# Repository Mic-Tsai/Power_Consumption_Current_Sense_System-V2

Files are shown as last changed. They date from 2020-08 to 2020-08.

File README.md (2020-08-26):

## Power Consumption | Current Sense System V2



Arduino based power consumption calculator. Print results as UART interface and OLED display, also have SD card to log data.

Maximum 8 differential channels, come out with 4x ADS1115 in one I2C bus. RGB OLED display (ST7789 130x160) results show as a real-time update also supports the SD card data log. 

** **Important** **

Before you log the power consumption results, the resistor value needs to be calculated by the multimeter. You can press the button to do the value change very quickly! 

After the data logging into the SD card, plot data into an image via a python script.
## 

Any question or need technical support:

* Contact me via mail (xbcke12345@gmail.com)
* If this project helping. Please generously support =)

   

##

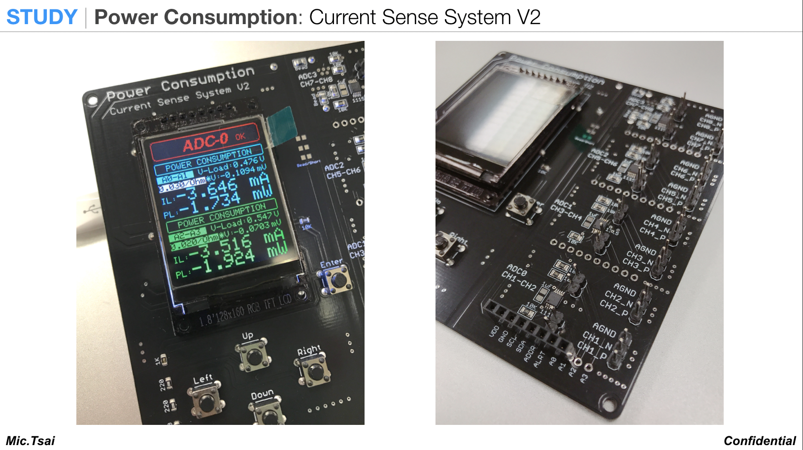
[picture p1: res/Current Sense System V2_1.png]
*Power Consumption | Current Sense System V2*

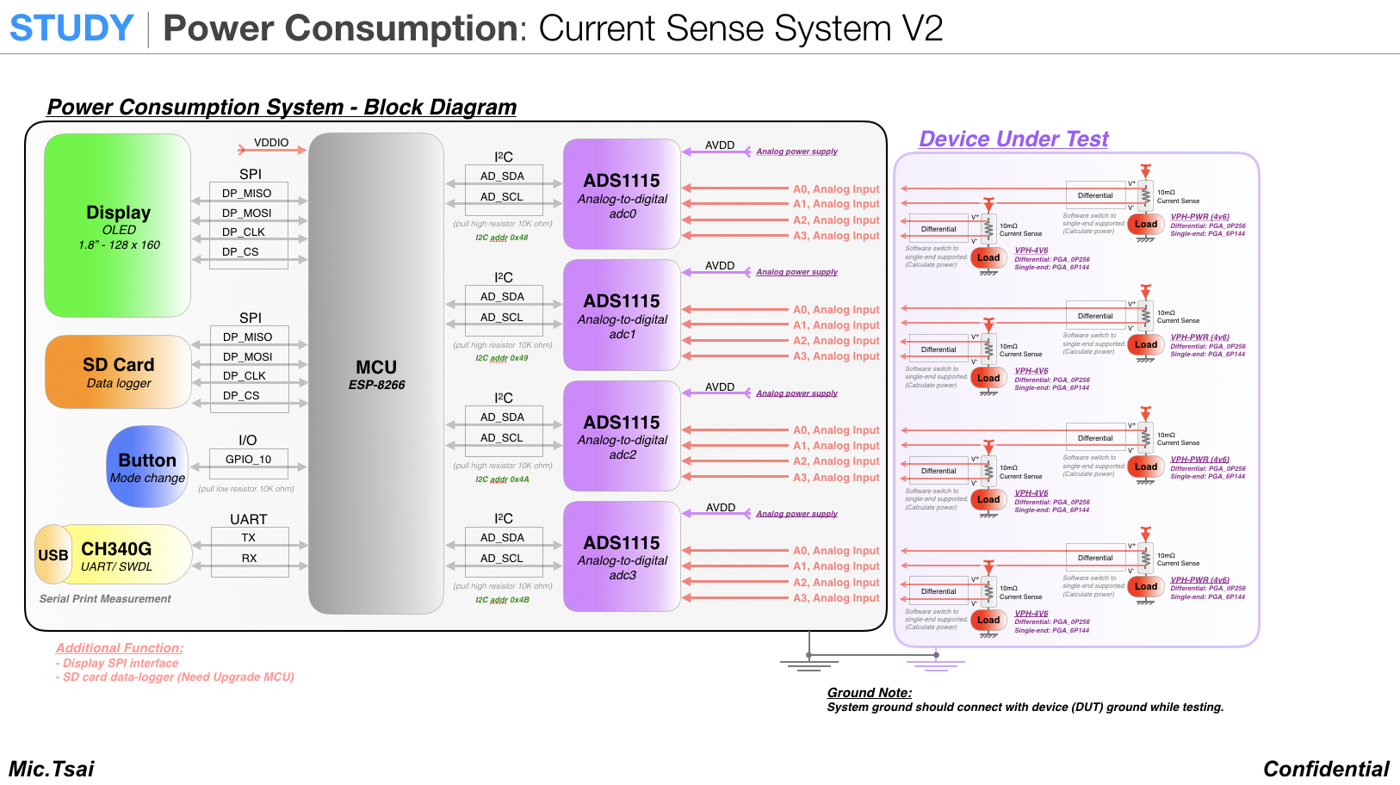
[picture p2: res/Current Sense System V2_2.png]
*Power Consumption | Current Sense System V2*

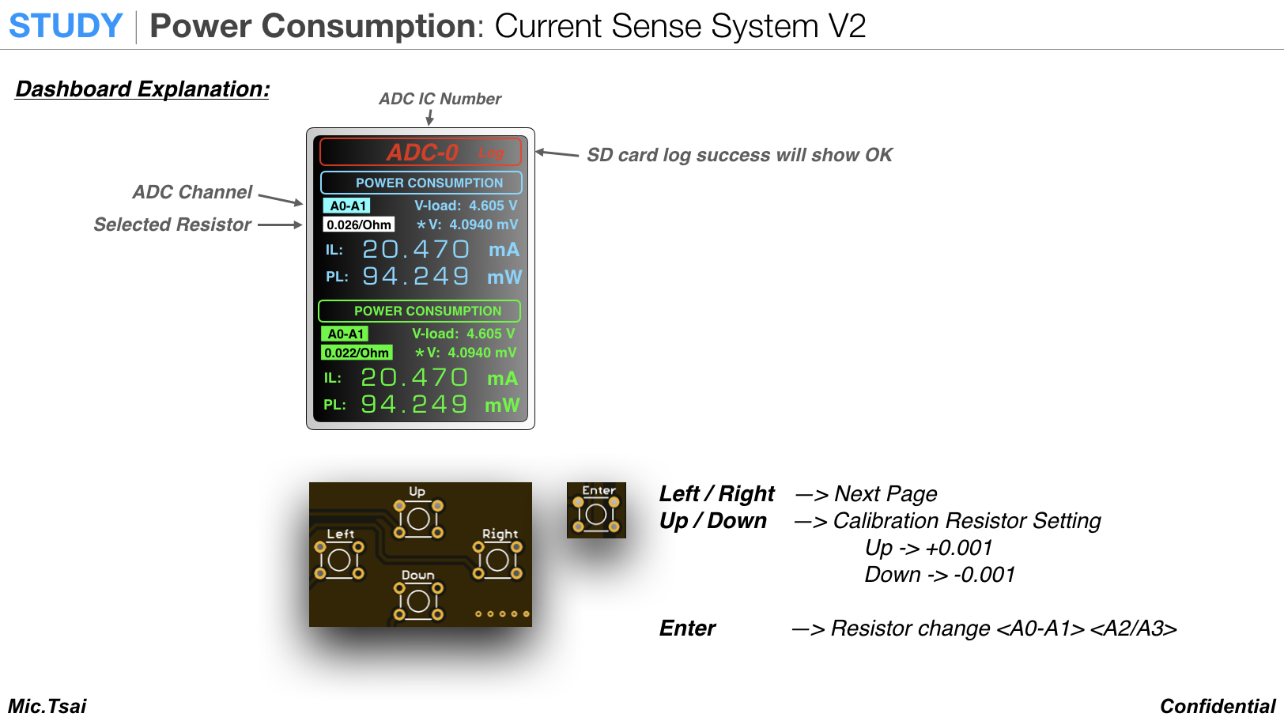
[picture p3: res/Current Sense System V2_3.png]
*Power Consumption | Current Sense System V2*

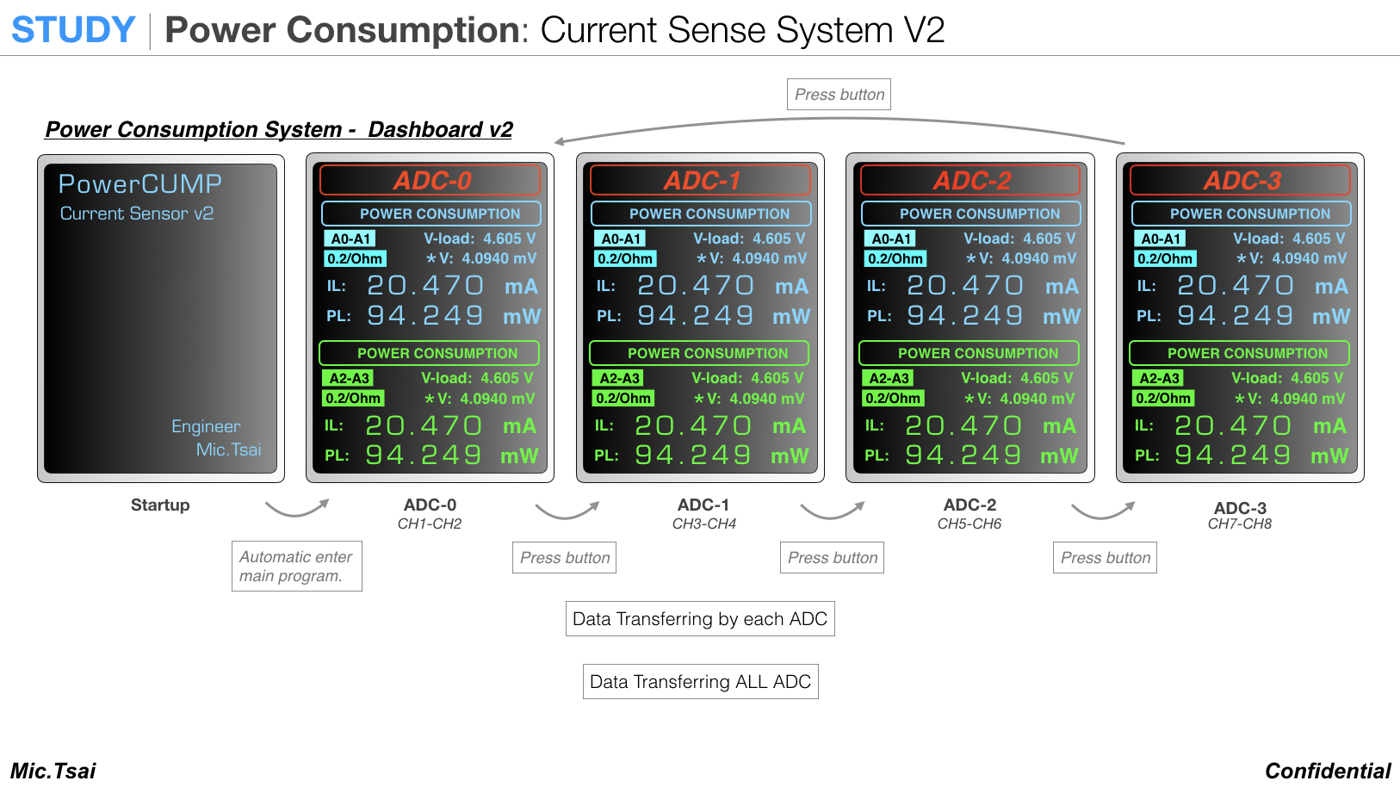
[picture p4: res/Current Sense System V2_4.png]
*Power Consumption | Current Sense System V2*

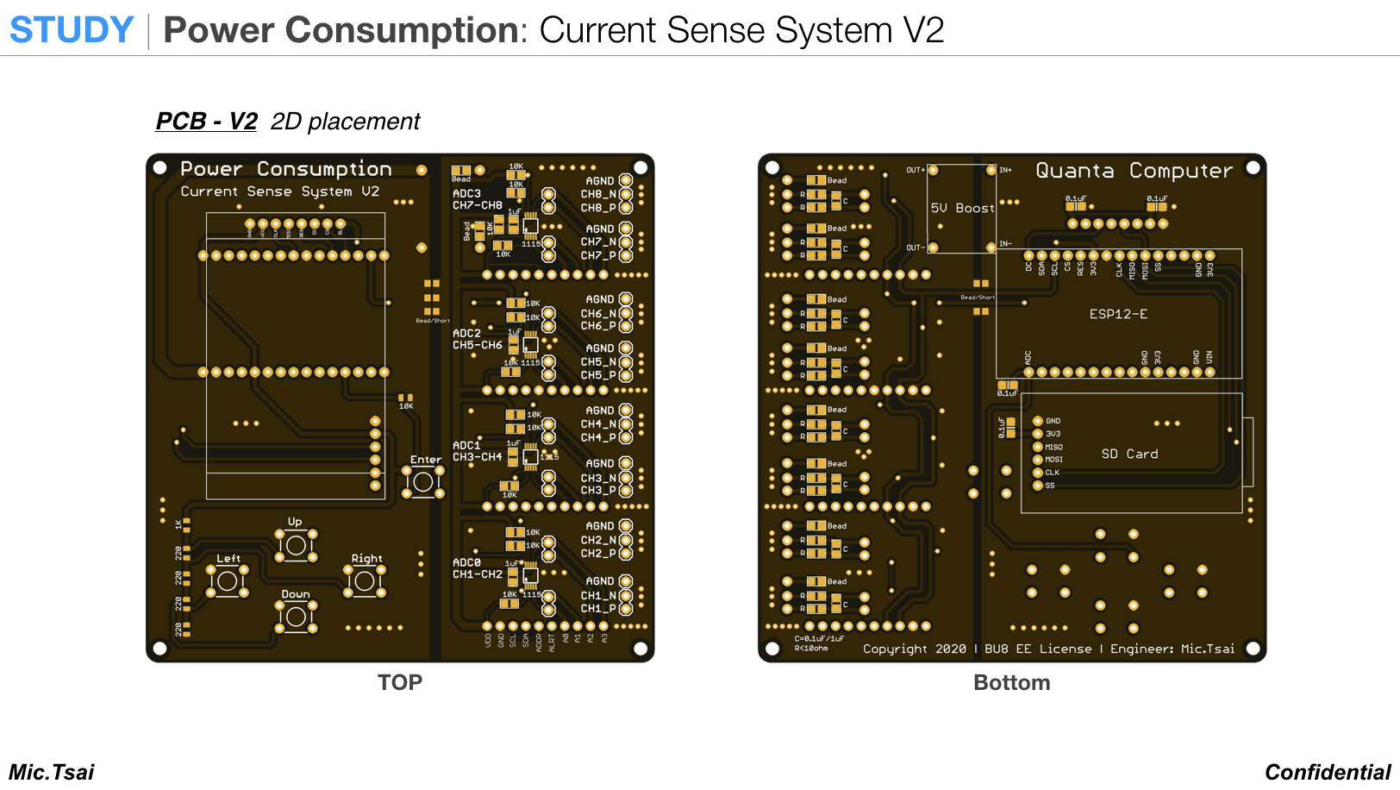
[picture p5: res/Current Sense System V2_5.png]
*Power Consumption | Current Sense System V2*

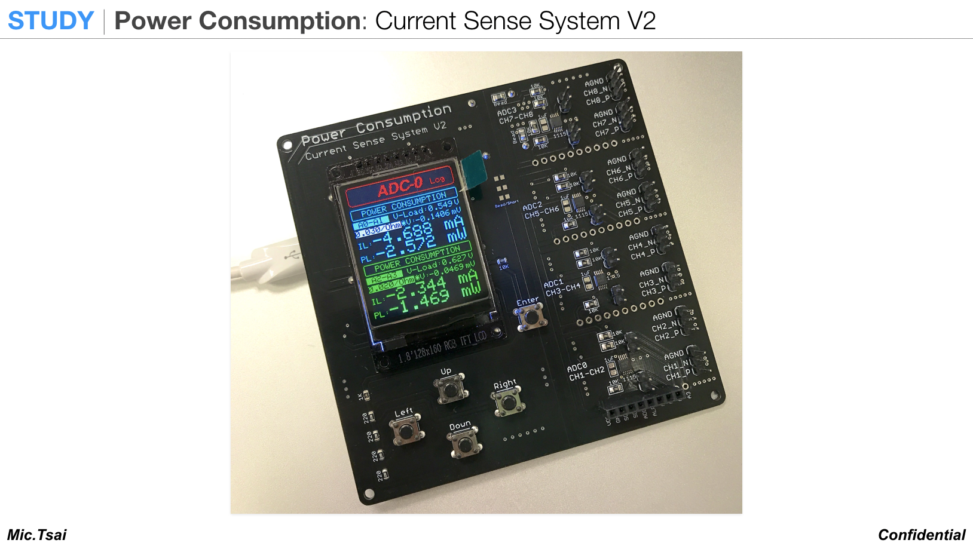
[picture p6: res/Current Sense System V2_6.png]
*Power Consumption | Current Sense System V2*

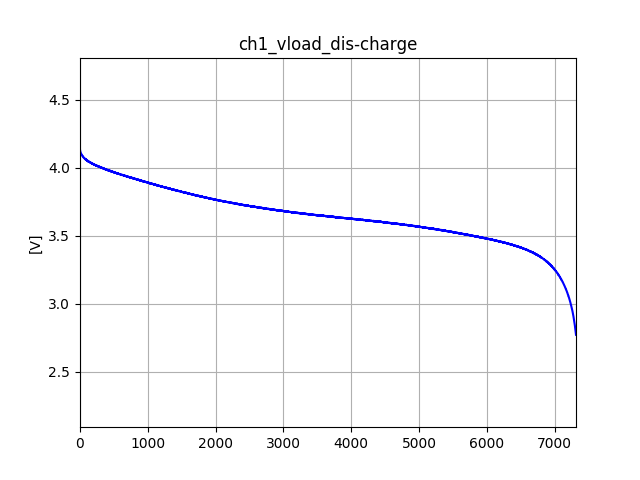
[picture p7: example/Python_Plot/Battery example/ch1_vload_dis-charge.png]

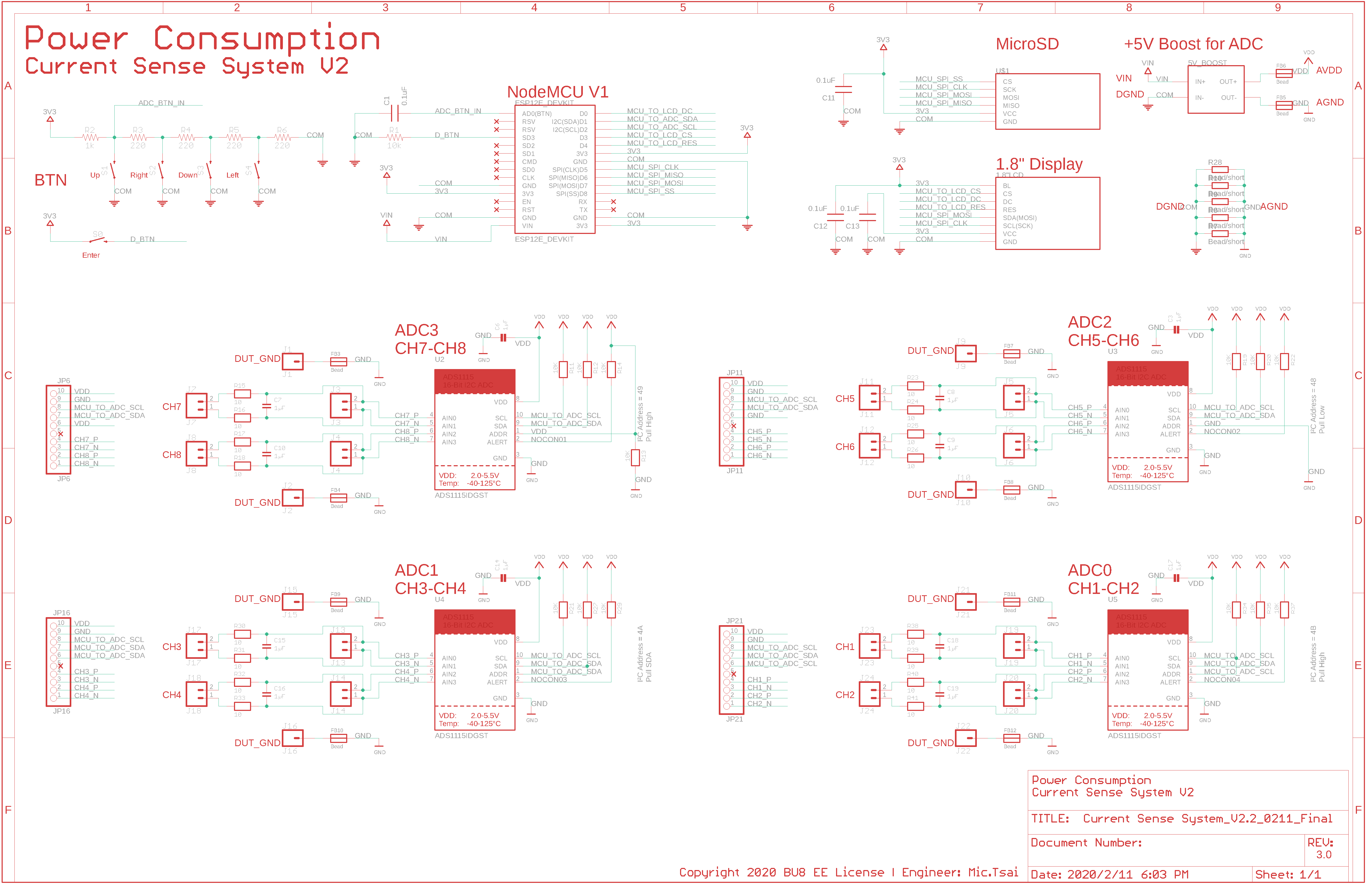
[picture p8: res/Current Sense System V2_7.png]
*Power Consumption | Current Sense System V2*

## 

>### License Information
>>This product is open source! Both, our hardware and software are open source and licensed under the following:
>>#### Hardware
>>>All hardware is released under [Creative Commons Share-alike 4.0 International](http://creativecommons.org/licenses/by-sa/4.0/).
>>#### Software 
>>>All software is released under the MIT License [http://opensource.org/licenses/MIT](http://opensource.org/licenses/MIT).
>>#### Documentation
>>>The documentation on this page is released under [Creative Commons Share-alike 4.0 International](http://creativecommons.org/licenses/by-sa/4.0/).

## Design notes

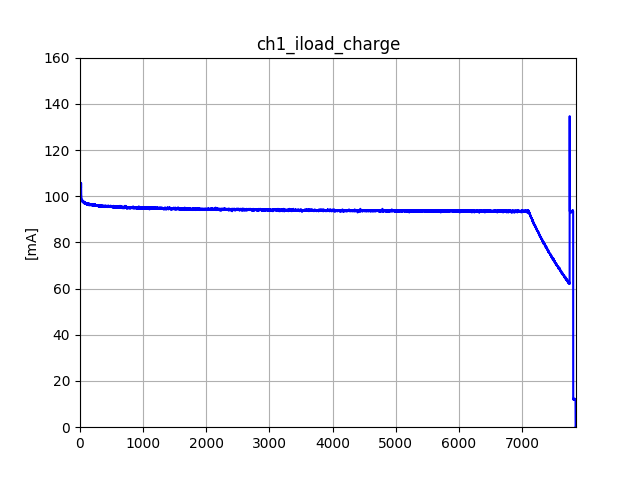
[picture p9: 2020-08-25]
example/Python_Plot/Battery example/ch1_iload_charge.png

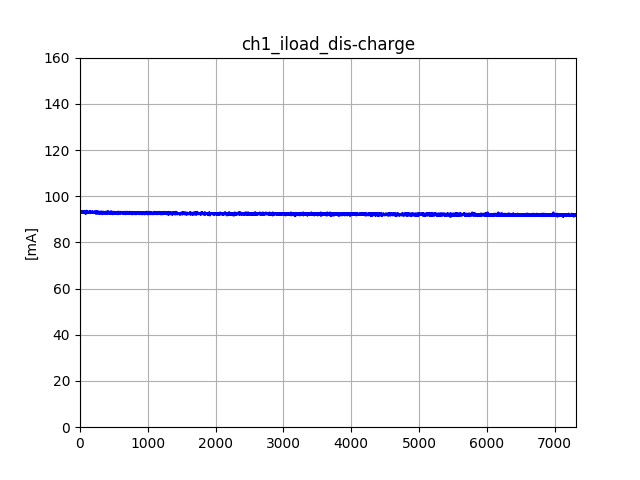
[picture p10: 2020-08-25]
example/Python_Plot/Battery example/plot/ch1_iload_dis-charge.png

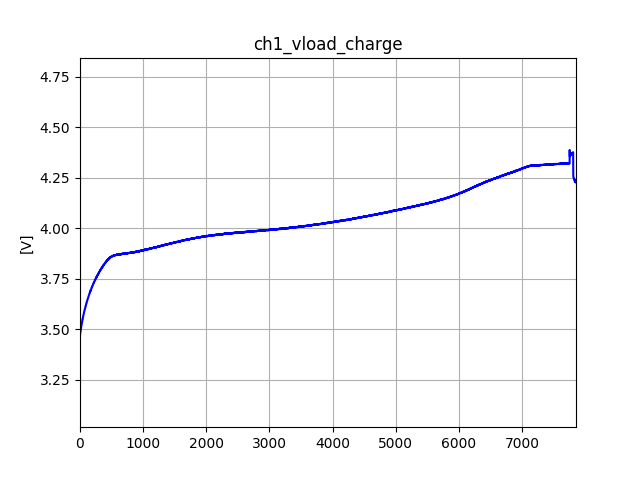
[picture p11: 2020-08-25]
example/Python_Plot/Battery example/plot/ch1_vload_charge.png

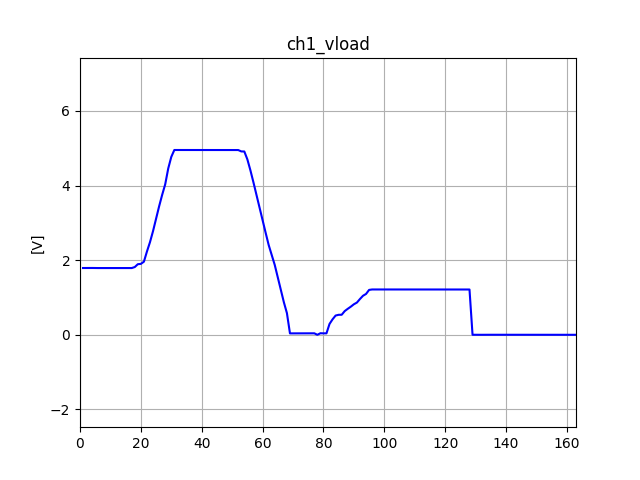
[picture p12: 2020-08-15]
example/Python_Plot/ex1/ch1_vload.png

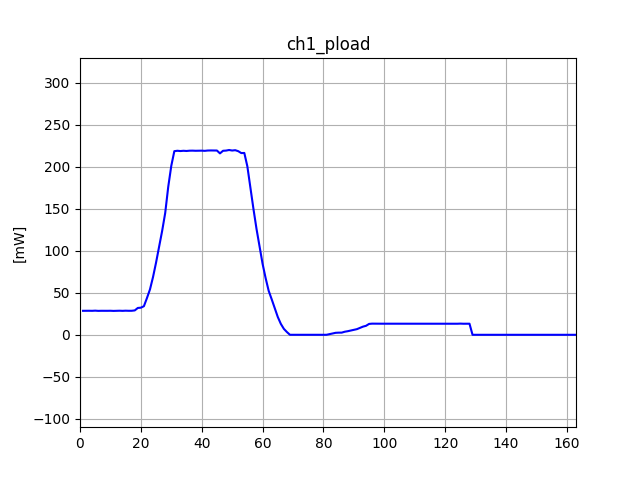
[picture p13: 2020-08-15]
example/Python_Plot/ex1/ch1_pload.png

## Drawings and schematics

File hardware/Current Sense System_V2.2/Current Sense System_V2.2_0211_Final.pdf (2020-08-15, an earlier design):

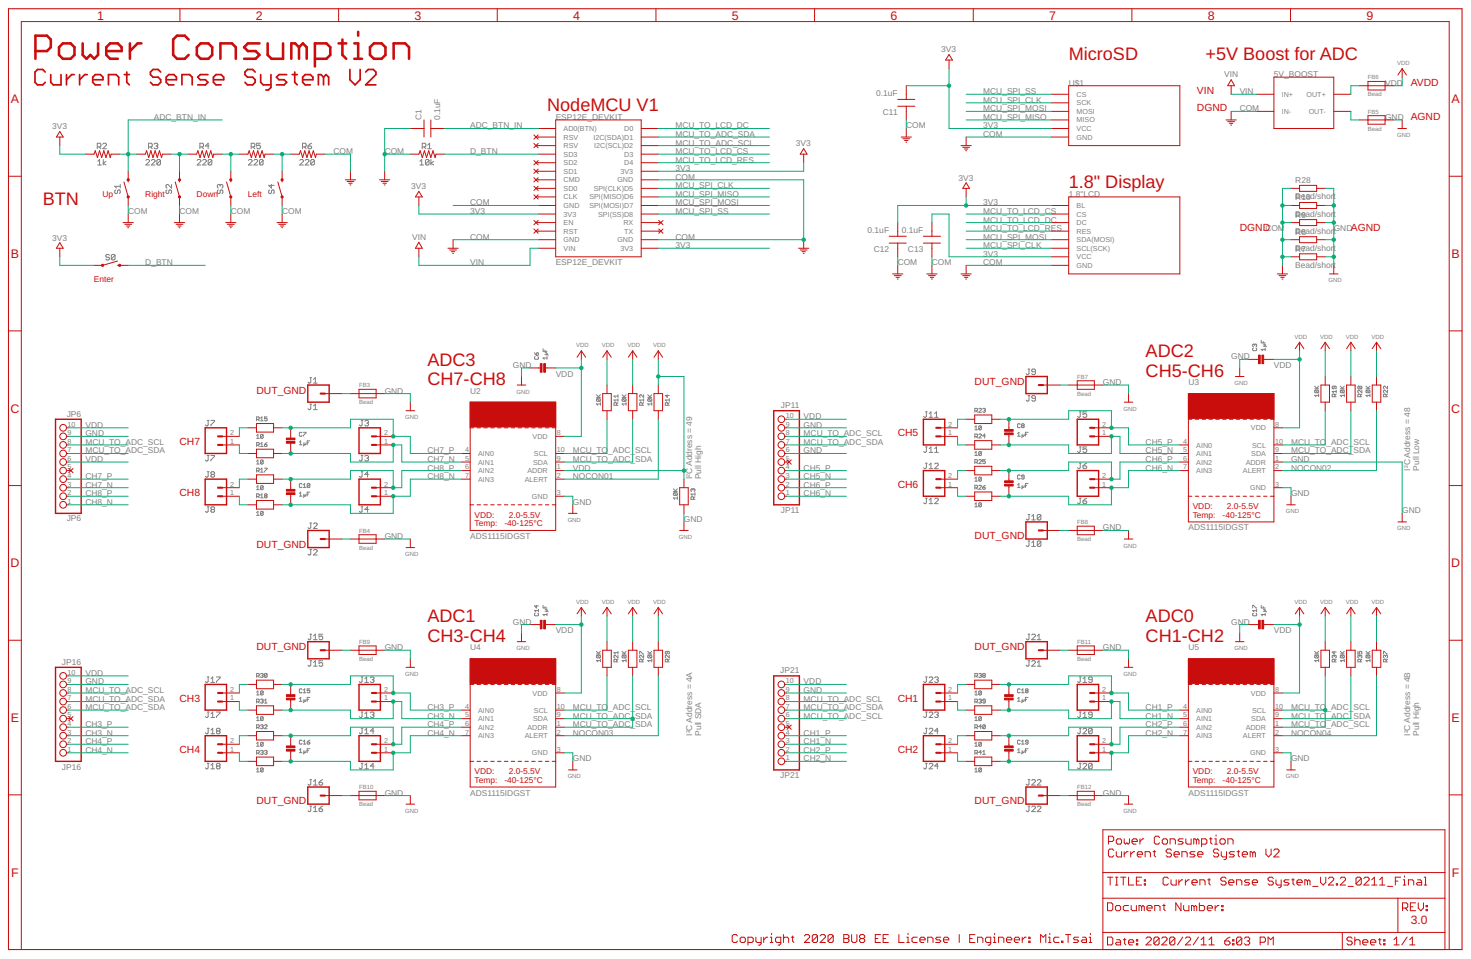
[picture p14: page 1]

SPI(CLK)D5 SPI(MISO)D6 SPI(MOSI)D7 SPI(SS)D8 RX

RES
SDA(MOSI) SCL(SCK) VCC GND

I²C Address = 48 Pull Low

I²C Address = 49 Pull High

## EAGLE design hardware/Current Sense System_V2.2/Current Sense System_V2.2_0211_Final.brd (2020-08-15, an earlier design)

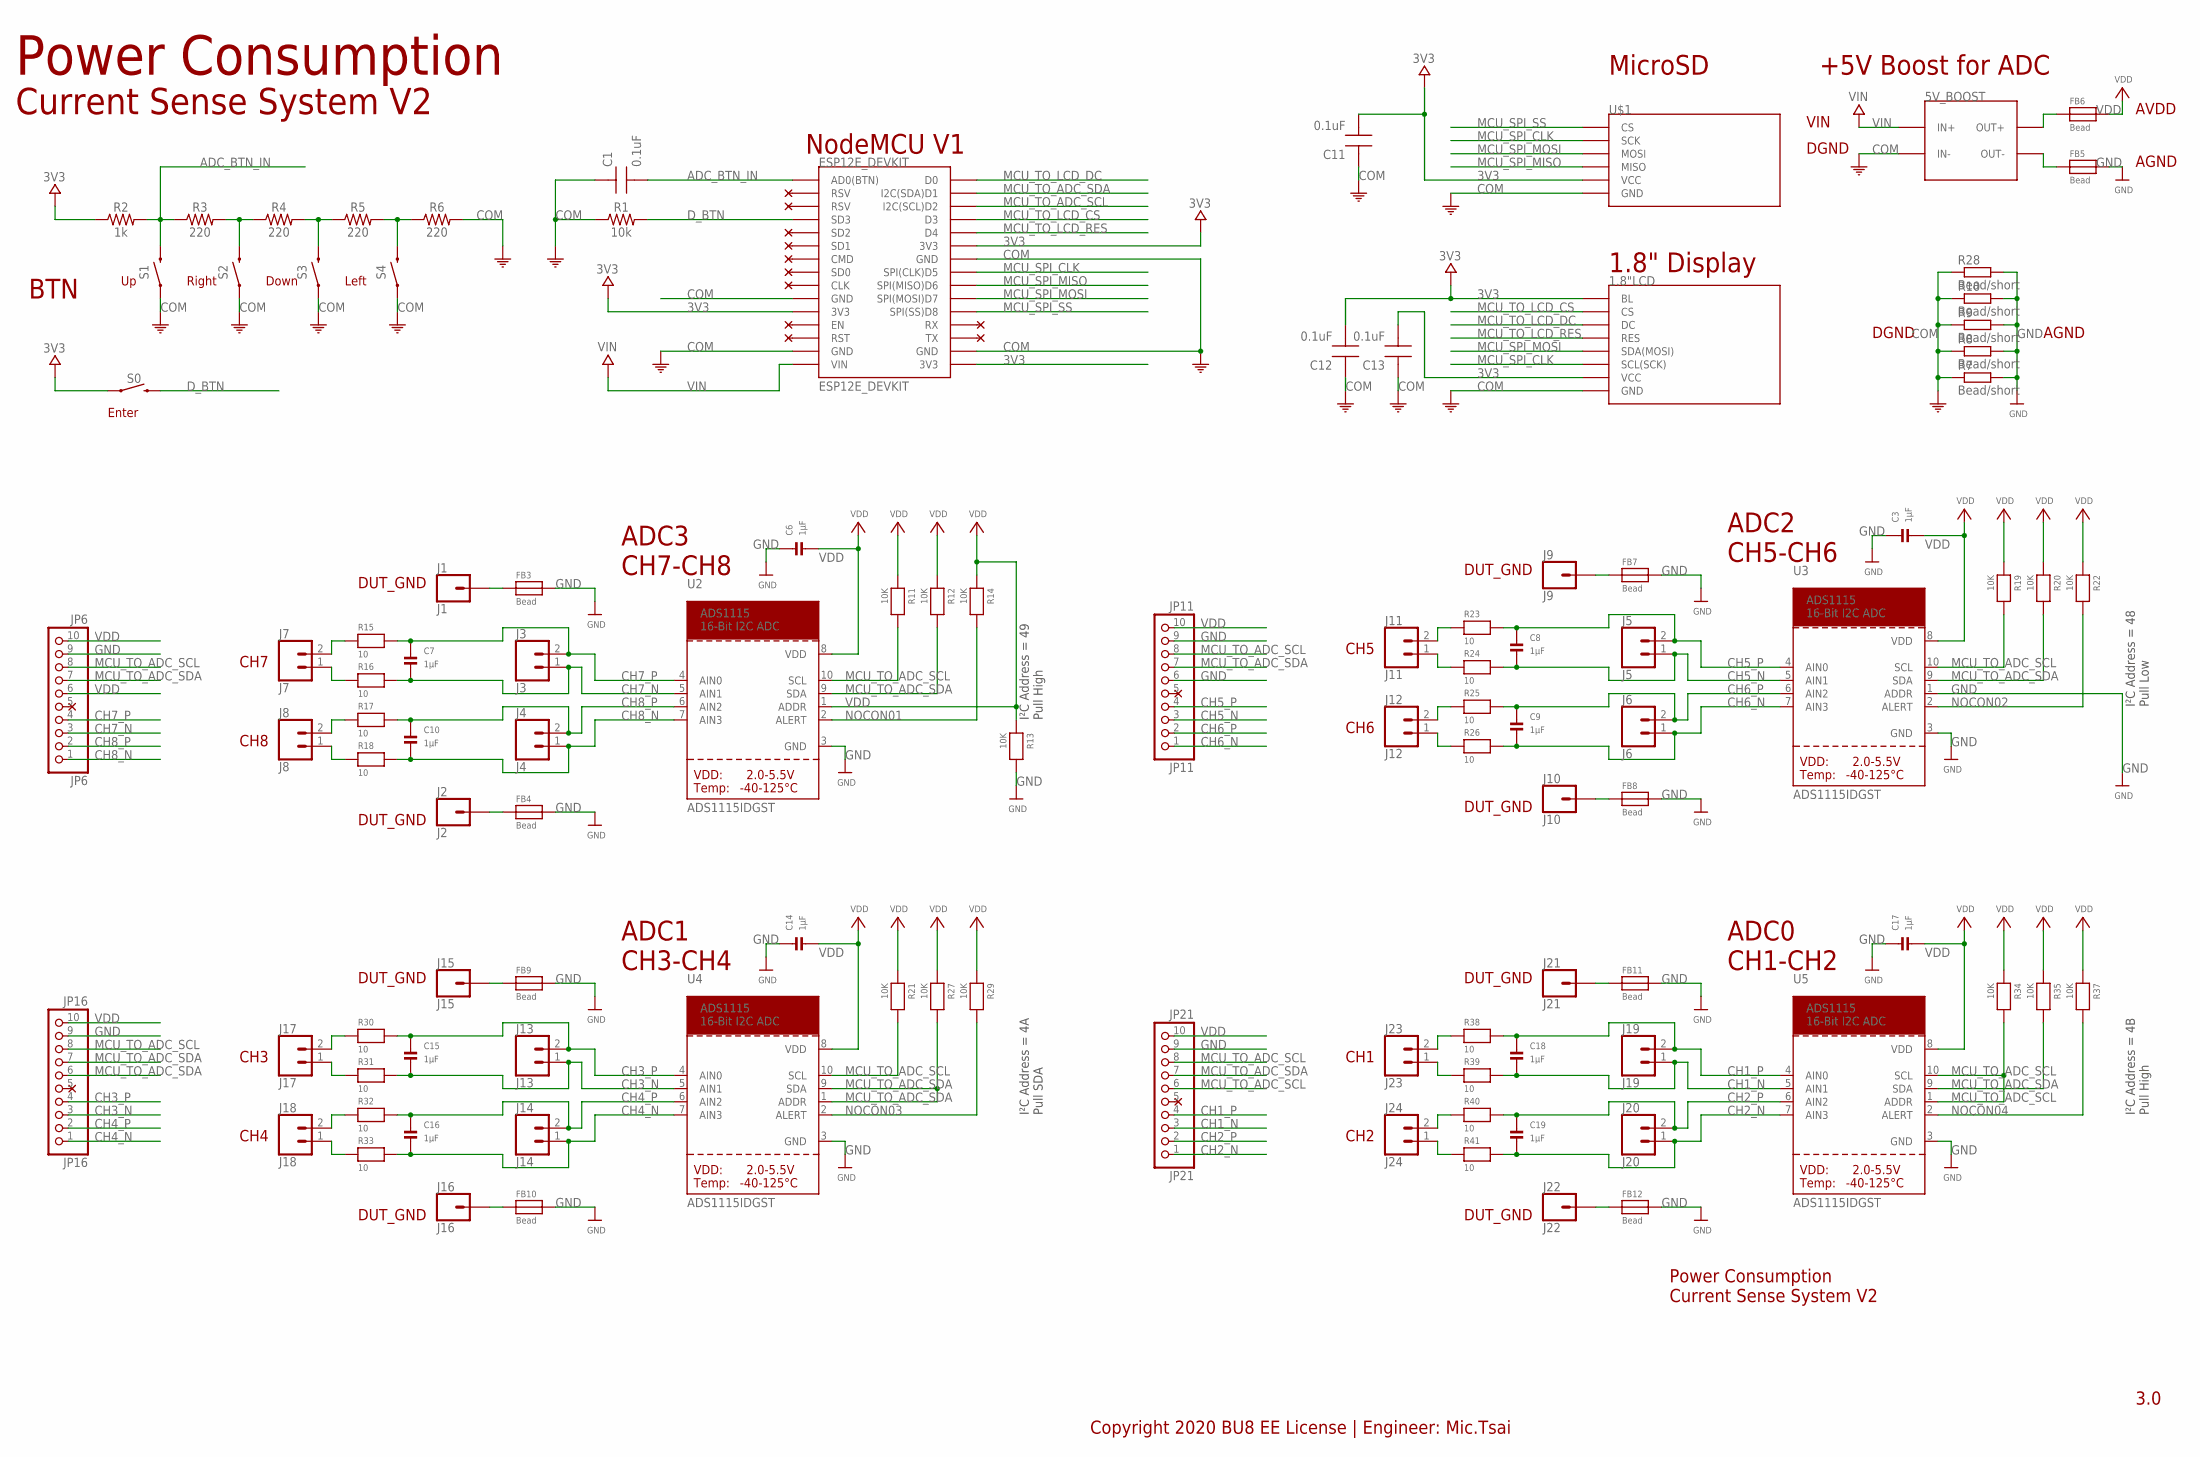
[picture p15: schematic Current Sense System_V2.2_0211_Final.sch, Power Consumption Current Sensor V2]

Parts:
1.8"LCD: 1.8"LCD"; 1.8"LCD
5V_BOOST: 5VBOOST"; 5VBOOST
C1, C11, C12, C13: 0.1uF; CAP0805-NP
C3, C6, C7, C8, C9, C10, C14, C15, C16, C17, C18, C19: 1µF; 0805
ESP12E_DEVKIT: ESP12E_DEVKIT
FB3, FB4, FB5, FB6, FB7, FB8, FB9, FB10, FB11, FB12: Bead; 0805
J1: J1; 1X01
J2: J2; 1X01
J3: J3; 1X02
J4: J4; 1X02
J5: J5; 1X02
J6: J6; 1X02
J7: J7; 1X02
J8: J8; 1X02
J9: J9; 1X01
J10: J10; 1X01
J11: J11; 1X02
J12: J12; 1X02
J13: J13; 1X02
J14: J14; 1X02
J15: J15; 1X01
J16: J16; 1X01
J17: J17; 1X02
J18: J18; 1X02
J19: J19; 1X02
J20: J20; 1X02
J21: J21; 1X01
J22: J22; 1X01
J23: J23; 1X02
J24: J24; 1X02
JP6: JP6; 1X10_ROUND70
JP11: JP11; 1X10_ROUND70
JP16: JP16; 1X10_ROUND70
JP21: JP21; 1X10_ROUND70
R1: 10k; 0805
R2: 1k; 0805
R3, R4, R5, R6: 220; 0805
R7, R8, R9, R10, R28: Bead/short; R0603
R11, R12, R13, R14, R19, R20, R21, R22, R27, R29, R34, R35, R37: 10K; 0805
R15, R16, R17, R18, R23, R24, R25, R26, R30, R31, R32, R33, R38, R39, R40, R41: 10; 0805
S0, S1, S2, S3, S4: MOMENTARY-SWITCH-SPST-PTH-6.0MM; TACTILE_SWITCH_PTH_6.0MM
U2, U3, U4, U5: ADS1115IDGST; MSOP10
U$1: MICROSD"; MICROSD

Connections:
3V3: 1.8"LCD.BL, 1.8"LCD.VCC(3V3) (VCC), C11.2, C12.2, C13.2, ESP12E_DEVKIT.3V3@0 (3V3), ESP12E_DEVKIT.3V3@1 (3V3), ESP12E_DEVKIT.3V3@2 (3V3), R2.1, S0.1, U$1.VCC(5V) (VCC)
ADC_BTN_IN: C1.2, ESP12E_DEVKIT.AD0 (AD0(BTN)), R2.2, R3.1, S1.3 (2)
CH1_N: C18.2, J19.1, JP21.3, R39.2, U5.5 (AIN1)
CH1_P: C18.1, J19.2, JP21.4, R38.2, U5.4 (AIN0)
CH2_N: C19.2, J20.1, JP21.1, R41.2, U5.7 (AIN3)
CH2_P: C19.1, J20.2, JP21.2, R40.2, U5.6 (AIN2)
CH3_N: C15.2, J13.1, JP16.3, R31.2, U4.5 (AIN1)
CH3_P: C15.1, J13.2, JP16.4, R30.2, U4.4 (AIN0)
CH4_N: C16.2, J14.1, JP16.1, R33.2, U4.7 (AIN3)
CH4_P: C16.1, J14.2, JP16.2, R32.2, U4.6 (AIN2)
CH5_N: C8.2, J5.1, JP11.3, R24.2, U3.5 (AIN1)
CH5_P: C8.1, J5.2, JP11.4, R23.2, U3.4 (AIN0)
CH6_N: C9.2, J6.1, JP11.1, R26.2, U3.7 (AIN3)
CH6_P: C9.1, J6.2, JP11.2, R25.2, U3.6 (AIN2)
CH7_N: C7.2, J3.1, JP6.3, R16.2, U2.5 (AIN1)
CH7_P: C7.1, J3.2, JP6.4, R15.2, U2.4 (AIN0)
CH8_N: C10.2, J4.1, JP6.1, R18.2, U2.7 (AIN3)
CH8_P: C10.1, J4.2, JP6.2, R17.2, U2.6 (AIN2)
COM: 1.8"LCD.GND, 5V_BOOST.IN-, C1.1, C11.1, C12.1, C13.1, ESP12E_DEVKIT.GND@0 (GND), ESP12E_DEVKIT.GND@1 (GND), ESP12E_DEVKIT.GND@2 (GND), ESP12E_DEVKIT.GND@3 (GND), R1.1, R6.2, R7.1, R8.1, R9.1, R10.1, R28.1, S1.1, S2.1, S3.1, S4.1, U$1.GND
D_BTN: ESP12E_DEVKIT.SD3, R1.2, S0.3 (2)
GND: C3.1, C6.1, C14.1, C17.1, FB3.2, FB4.2, FB5.2, FB7.2, FB8.2, FB9.2, FB10.2, FB11.2, FB12.2, JP6.9, JP11.6, JP11.9, JP16.9, JP21.9, R7.2, R8.2, R9.2, R10.2, R13.2, R28.2, U2.3 (GND), U3.1 (ADDR), U3.3 (GND), U4.3 (GND), U5.3 (GND)
MCU_SPI_CLK: 1.8"LCD.SCL(SCK), ESP12E_DEVKIT.D5 (SPI(CLK)D5), U$1.SCK
MCU_SPI_MISO: ESP12E_DEVKIT.D6 (SPI(MISO)D6), U$1.MISO
MCU_SPI_MOSI: 1.8"LCD.SDA(MOSI), ESP12E_DEVKIT.D7 (SPI(MOSI)D7), U$1.MOSI
MCU_SPI_SS: ESP12E_DEVKIT.D8 (SPI(SS)D8), U$1.CS
MCU_TO_ADC_SCL: ESP12E_DEVKIT.D2 (I2C(SCL)D2), JP6.8, JP11.8, JP16.8, JP21.6, JP21.8, R11.2, R19.2, R21.2, R34.2, U2.10 (SCL), U3.10 (SCL), U4.10 (SCL), U5.1 (ADDR), U5.10 (SCL)
MCU_TO_ADC_SDA: ESP12E_DEVKIT.D1 (I2C(SDA)D1), JP6.7, JP11.7, JP16.6, JP16.7, JP21.7, R12.2, R20.2, R27.2, R35.2, U2.9 (SDA), U3.9 (SDA), U4.1 (ADDR), U4.9 (SDA), U5.9 (SDA)
MCU_TO_LCD_CS: 1.8"LCD.CS, ESP12E_DEVKIT.D3
MCU_TO_LCD_DC: 1.8"LCD.DC, ESP12E_DEVKIT.D0
MCU_TO_LCD_RES: 1.8"LCD.RES, ESP12E_DEVKIT.D4
unnamed: FB3.1, J1.1
unnamed: FB4.1, J2.1
unnamed: J7.2, R15.1
unnamed: J7.1, R16.1
unnamed: J8.2, R17.1
unnamed: J8.1, R18.1
unnamed: 5V_BOOST.OUT-, FB5.1
unnamed: 5V_BOOST.OUT+, FB6.1
unnamed: FB7.1, J9.1
unnamed: FB8.1, J10.1
unnamed: J11.2, R23.1
unnamed: J11.1, R24.1
unnamed: J12.2, R25.1
unnamed: J12.1, R26.1
unnamed: FB9.1, J15.1
unnamed: R3.2, R4.1, S2.3 (2)
unnamed: R4.2, R5.1, S3.3 (2)
unnamed: R5.2, R6.1, S4.3 (2)
unnamed: FB10.1, J16.1
unnamed: J17.2, R30.1
unnamed: J17.1, R31.1
unnamed: J18.2, R32.1
unnamed: J18.1, R33.1
unnamed: FB11.1, J21.1
unnamed: FB12.1, J22.1
unnamed: J23.2, R38.1
unnamed: J23.1, R39.1
unnamed: J24.2, R40.1
unnamed: J24.1, R41.1
NOCON01: R14.2, U2.2 (ALERT)
NOCON02: R22.2, U3.2 (ALERT)
NOCON03: R29.2, U4.2 (ALERT)
NOCON04: R37.2, U5.2 (ALERT)
VDD: C3.2, C6.2, C14.2, C17.2, FB6.2, JP6.6, JP6.10, JP11.10, JP16.10, JP21.10, R11.1, R12.1, R13.1, R14.1, R19.1, R20.1, R21.1, R22.1, R27.1, R29.1, R34.1, R35.1, R37.1, U2.1 (ADDR), U2.8 (VDD), U3.8 (VDD), U4.8 (VDD), U5.8 (VDD)
VIN: 5V_BOOST.IN+, ESP12E_DEVKIT.VIN

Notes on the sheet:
Power Consumption
3.0
NodeMCU V1
+5V Boost for ADC
Power Consumption Current Sense System V2
Current Sense System V2
BTN
Right
Down
Left
Enter
1.8" Display
MicroSD
I²C Address = 49 Pull High
ADC3 CH7-CH8
ADS1115 16-Bit I2C ADC
CH7
CH8
DUT_GND
I²C Address = 48 Pull Low
ADC2 CH5-CH6
CH5
CH6
I²C Address = 4A Pull SDA
ADC1 CH3-CH4
CH3
CH4
I²C Address = 4B Pull High
ADC0 CH1-CH2
CH1
CH2
AVDD
AGND
VIN
DGND
Copyright 2020 BU8 EE License | Engineer: Mic.Tsai

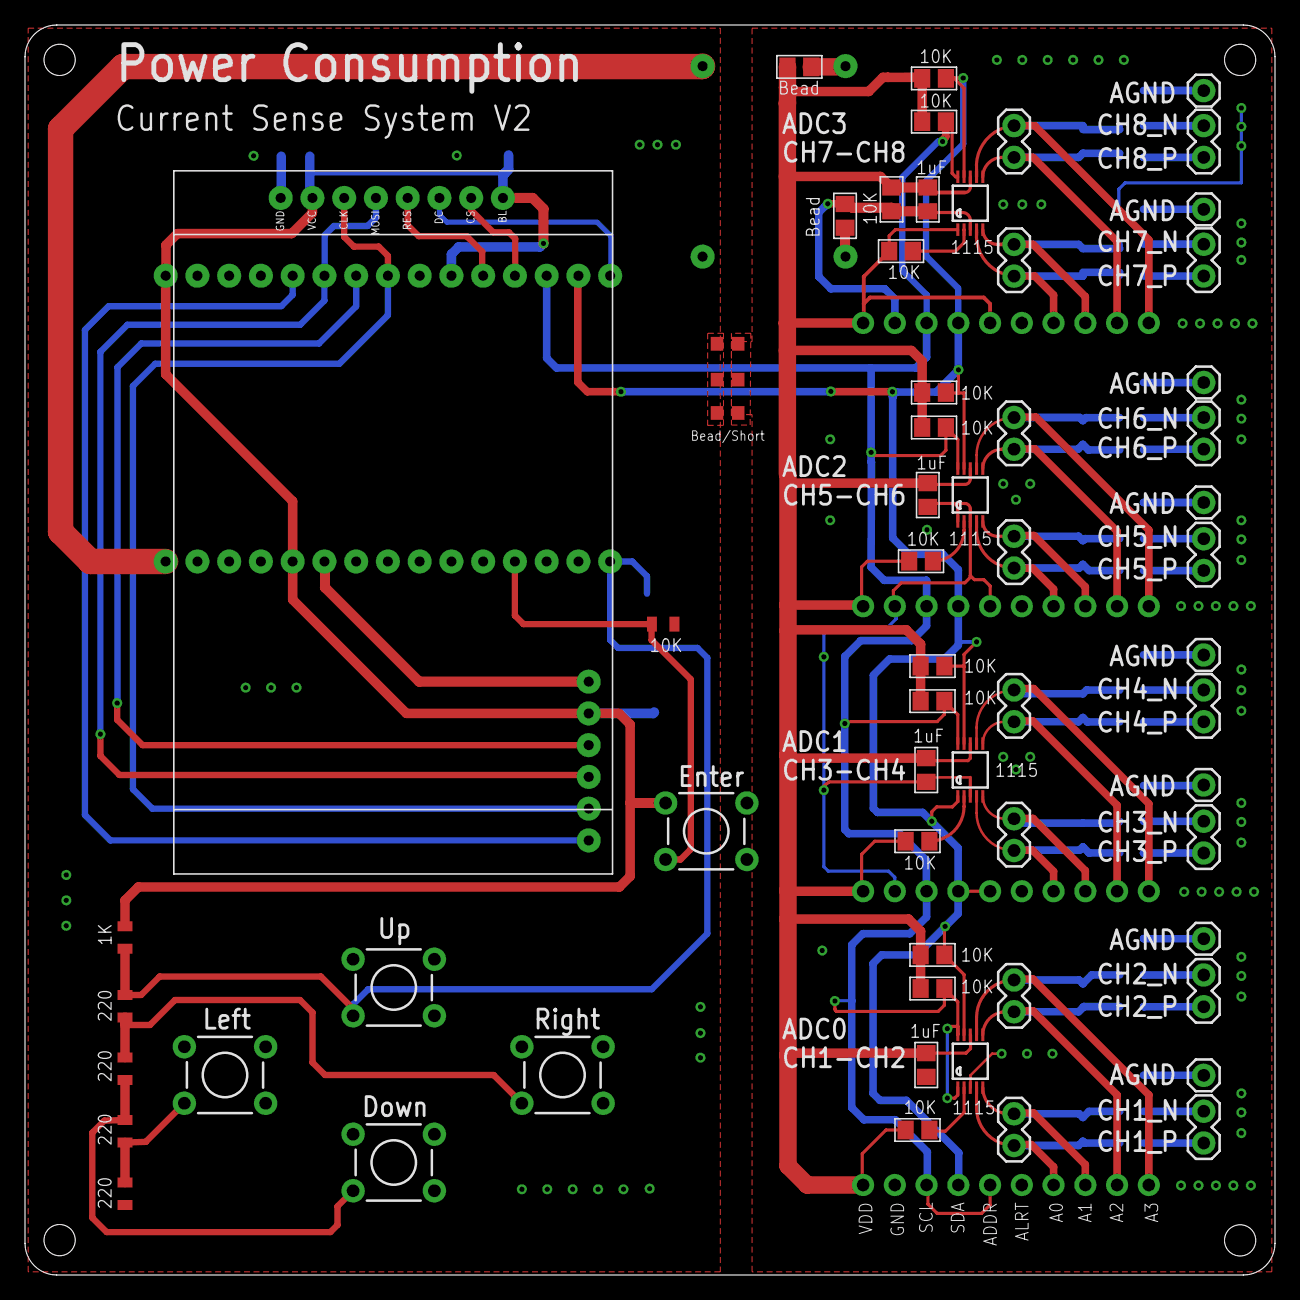
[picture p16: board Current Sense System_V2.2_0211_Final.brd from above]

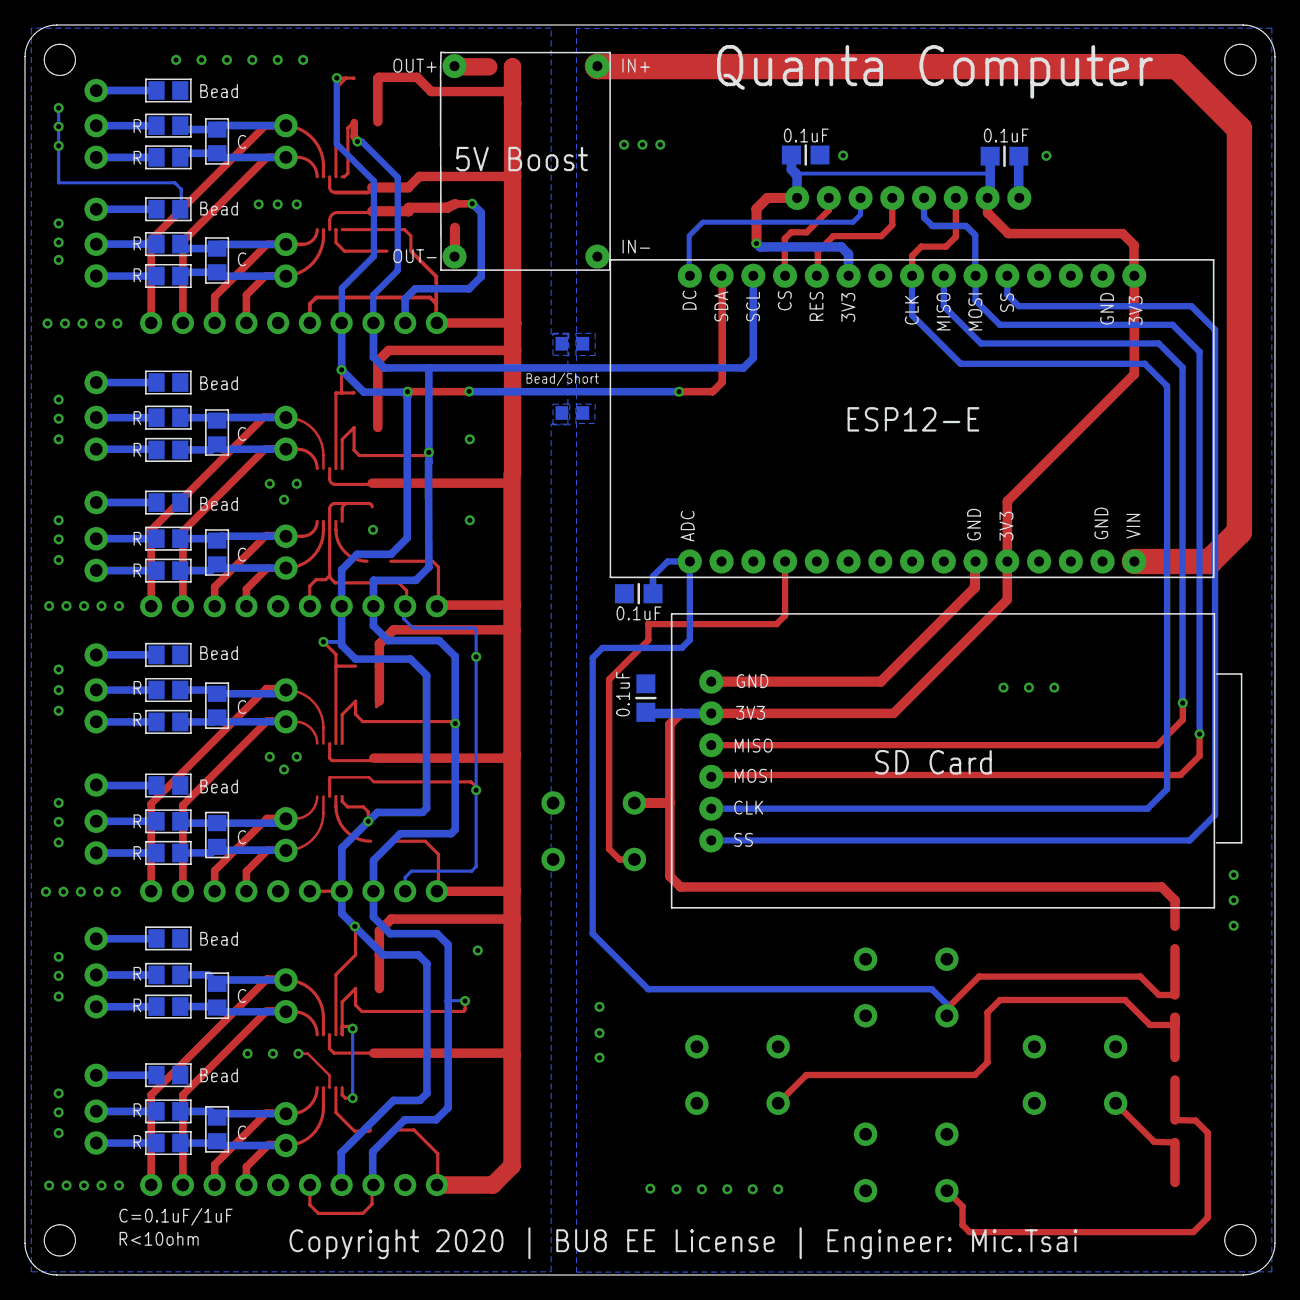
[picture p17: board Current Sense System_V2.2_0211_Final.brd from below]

Board: 2 copper layers, 100.0 x 100.0 mm, 107 parts (41 on the bottom side), 65 nets.

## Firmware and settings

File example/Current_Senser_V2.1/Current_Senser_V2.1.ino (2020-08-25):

// ###################################################################################
// # Project: 8WA Current Senser
// # Engineer:  Mic.Tsai
// # Date:  25 August 2020
// # Objective: Dev.board
// # Usage: ESP8266
// ###################################################################################
// # Mode select pin must serial 10k to GND (Floating will NOT trigger ADC work)
// ###################################################################################
// # Update Note:
// # Version 2.1: Save Data And Flash Dashboard By Minute
// ###################################################################################
// # Set Current Sensor Value
// # 100 (0.1ohm)
// ###################################################################################

float ADC0_A0_A1_Resistor = 0;   float ADC0_A0_A1_Resistor_Change = 115;
float ADC0_A2_A3_Resistor = 0;   float ADC0_A2_A3_Resistor_Change = 115;

float ADC1_A0_A1_Resistor = 0;   float ADC1_A0_A1_Resistor_Change = 30; 
float ADC1_A2_A3_Resistor = 0;   float ADC1_A2_A3_Resistor_Change = 20; 

float ADC2_A0_A1_Resistor = 0;   float ADC2_A0_A1_Resistor_Change = 30; 
float ADC2_A2_A3_Resistor = 0;   float ADC2_A2_A3_Resistor_Change = 20; 

float ADC3_A0_A1_Resistor = 0;   float ADC3_A0_A1_Resistor_Change = 30; 
float ADC3_A2_A3_Resistor = 0;   float ADC3_A2_A3_Resistor_Change = 20; 

// ###################################################################################
// ###################################################################################

#include "ADS1115.h"

//Declare 4x adc board as following I2C address.
ADS1115 adc0(0x4B);
ADS1115 adc1(0x4A);
ADS1115 adc2(0x48);
ADS1115 adc3(0x49); // NEED CONNECT 2x MORE ADS1115, SINGLE ADC3 will not recognize the addrss.


//Mode change declaration
const int  buttonPin = 10;    // Mode change # Mode select pin must serial 10k to GND (Floating will NOT trigger ADC work)
int sensorValue;

//Variables will change:
int buttonPushCounterDigi = 0;   // counter for the number of button presses
int buttonState = 0;         // current state of the button
int lastButtonState = 0;     // previous state of the button

//Analog used
int buttonPushCounter = 0;   // counter for the number of button presses

//Display ST7789 130x160
#include <Adafruit_GFX.h>    // Core graphics library
#include <Adafruit_ST7789.h> // Hardware-specific library for ST7789
#include <SPI.h>

#define TFT_RST   2     // TFT RST pin is connected to NodeMCU pin D4 (GPIO2)
#define TFT_CS    0     // TFT CS  pin is connected to NodeMCU pin D4 (GPIO0)
#define TFT_DC    16 

// HARDWARE SPI pins
Adafruit_ST7789 tft = Adafruit_ST7789( TFT_CS, TFT_DC, TFT_RST);

// Set fonts
#include <stdio.h>
#include <Fonts/FreeSansBoldOblique9pt7b.h>

// Set SD card
#include <SD.h>
const int chipSelect = 15;

// Set print_time
unsigned long print_time;

// Set for sd logging time please change the value here.
int sd_log_time=60000;
int display_update_time=50000;

// Set for sd logging time
int TimerLast=0;
int TimerNow=0;
int Timer=60000;

// Set for display update time
int TimerLast2=0;
int TimerNow2=0;
int Timer2=0;

// -----------------------------------------------------------------------------
// Arduino-Setup
// -----------------------------------------------------------------------------

void setup() {   
   
    //I2Cdev::begin();  // join I2C bus
    Wire.begin(5,4);
    Serial.begin(9600); // initialize serial communication 
    Serial.println("Testing device connections...");
    delay(200);

    Serial.println(adc0.testConnection() ? "ADS1115-adc0 connection successful" : "ADS1115-adc0 connection failed");
    Serial.println(adc1.testConnection() ? "ADS1115-adc1 connection successful" : "ADS1115-adc1 connection failed");
    Serial.println(adc2.testConnection() ? "ADS1115-adc2 connection successful" : "ADS1115-adc2 connection failed");
    Serial.println(adc3.testConnection() ? "ADS1115-adc3 connection successful" : "ADS1115-adc3 connection failed");

    // see if the card is present and can be initialized:
    Serial.print("Initializing SD card...");
    Serial.println(SD.begin(chipSelect) ? "card initialized." : "Card failed, or not present");

    // initialize ADS1115 16 bit A/D chip
    adc0.initialize(); 
    adc1.initialize();
    adc2.initialize();
    adc3.initialize();

    // Continuous sampling
    adc0.setMode(ADS1115_MODE_CONTINUOUS);
    adc1.setMode(ADS1115_MODE_CONTINUOUS);
    adc2.setMode(ADS1115_MODE_CONTINUOUS);
    adc3.setMode(ADS1115_MODE_CONTINUOUS);

    // Slow things down so that we can see that the "poll for conversion" code works
    adc0.setRate(ADS1115_RATE_250);
    adc1.setRate(ADS1115_RATE_250);
    adc2.setRate(ADS1115_RATE_250);
    adc3.setRate(ADS1115_RATE_250);

    //Mode change button input
    pinMode(buttonPin, INPUT);
    buttonPushCounter = 0;
    buttonPushCounterDigi = 0;

    //Display show...
    Serial.print(F("Hello! ST77xx TFT Test"));
    tft.init(130 , 162);  // 128x160 will show garbage image in corner.
    Serial.println(F("Initialized"));

    uint16_t time = millis();
    tft.fillScreen(ST77XX_BLACK);
    time = millis() - time;
    
    Serial.println(time, DEC);
    delay(500);
    tft.setTextWrap(false);
    tft.invertDisplay(false);      
    tft.fillScreen(ST77XX_BLACK);
    tft.setFont(&FreeSansBoldOblique9pt7b);
      
    // Display Project Infomation
    tft.setTextColor(ST77XX_CYAN); tft.setTextSize(1); tft.setCursor(1, 20);  tft.println("PowerCUMP");
    tft.setFont();
    tft.setTextColor(ST77XX_CYAN); tft.setTextSize(1); tft.setCursor(2, 31);  tft.println("Current Senser v2"); delay(1000);
    tft.setTextColor(ST77XX_CYAN); tft.setTextSize(1); tft.setCursor(62, 136);  tft.println("Engineer");
    tft.setTextColor(ST77XX_CYAN); tft.setTextSize(1); tft.setCursor(77, 150);  tft.println("Mic.Tsai"); delay(1000);
    tft.invertDisplay(false); delay(1000);
    tft.fillScreen(ST77XX_BLACK);
    tft.setFont();

    Serial.println("System Installation OK:");


    ADC0_A0_A1_Resistor = ADC0_A0_A1_Resistor_Change /1000 ; ADC0_A2_A3_Resistor = ADC0_A2_A3_Resistor_Change /1000 ;
    Serial.println(ADC0_A0_A1_Resistor_Change, 4); Serial.println(ADC0_A2_A3_Resistor_Change, 4);

    ADC1_A0_A1_Resistor = ADC1_A0_A1_Resistor_Change /1000 ; ADC1_A2_A3_Resistor = ADC1_A2_A3_Resistor_Change /1000 ;
    Serial.println(ADC1_A0_A1_Resistor_Change, 4); Serial.println(ADC1_A2_A3_Resistor_Change, 4);

    ADC2_A0_A1_Resistor = ADC2_A0_A1_Resistor_Change /1000 ; ADC2_A2_A3_Resistor = ADC2_A2_A3_Resistor_Change /1000 ;
    Serial.println(ADC2_A0_A1_Resistor_Change, 4); Serial.println(ADC2_A2_A3_Resistor_Change, 4);

    ADC3_A0_A1_Resistor = ADC3_A0_A1_Resistor_Change /1000 ; ADC3_A2_A3_Resistor = ADC3_A2_A3_Resistor_Change /1000 ;
    Serial.println(ADC3_A0_A1_Resistor_Change, 4); Serial.println(ADC3_A2_A3_Resistor_Change, 4);



    // SD card data log for Start Label
    SD.begin(chipSelect);
    File dataFile = SD.open("Log-ADC0-CH1-CH2.txt", FILE_WRITE);
  
    // if the file is available, write to it:
    if (dataFile) {
        
        dataFile.println("Power Consumption Start Recording:");
        dataFile.close();
        Serial.print("| Log SD done!");
        
        //Print_time
        print_time = millis();
        Serial.print(" "); Serial.print(print_time); Serial.print("ms ");

        tft.setTextSize(1);tft.setTextColor(ST77XX_RED); 
        tft.fillRect(100+2, 10+1, 25, 10, ST77XX_BLACK);
        tft.setCursor(100+2, 10+1 ); tft.print("OK");
     }
        // if the file isn't open, pop up an error:
        else {
          Serial.println("| error opening datalog.txt");
        
          tft.setTextSize(1);tft.setTextColor(ST77XX_RED); 
          tft.fillRect(100+2, 10+1, 25, 10, ST77XX_BLACK);
          tft.setCursor(100+2, 10+1 ); tft.print("FAIL");        
          }  
}

// -----------------------------------------------------------------------------
// Arduino-Loop
// -----------------------------------------------------------------------------

void loop() {
  
//>>>>>>>>>>>>>>>>>>>>>>>>>>>>>>>>>>>>>>>>>>>>>>
//>>>>>>>>>>>>>>>>>>>>>>>>>>>>>>>>>>>>>>>>>>>>>>
//>>>>>>>>>>>>>>>>>>>>>>>>>>>>>>>>>>>>>>>>>>>>>>
  // Status change mode

  buttonState = digitalRead(buttonPin);

  if (buttonState != lastButtonState) {
    if (buttonState == HIGH) {
      buttonPushCounterDigi++;
      tft.fillScreen(ST77XX_BLACK);
    }
    delay(10);
  } 
  lastButtonState = buttonState;
//  Serial.println(buttonPushCounterDigi);
  
//>>>>>>>>>>>>>>>>>>>>>>>>>>>>>>>>>>>>>>>>>>>>>>
  if (buttonPushCounterDigi > 1) {
    buttonPushCounterDigi = 0;
  }
  if (buttonPushCounterDigi < 0) {
    buttonPushCounterDigi = 1;
  }
//>>>>>>>>>>>>>>>>>>>>>>>>>>>>>>>>>>>>>>>>>>>>>>

  // 4x button reading
  sensorValue = analogRead(A0);

  if (sensorValue <= 430){
      delay(30);        // Reads for stability

      if (sensorValue <= 10){   
      delay(30);        // Reads for stability

                  if ( buttonPushCounter == 0 && buttonPushCounterDigi == 0){
                  Serial.println("  ");
                  Serial.print("UP Button Pressed: value:"); Serial.println(sensorValue);
                    ADC0_A0_A1_Resistor = ADC0_A0_A1_Resistor + (0.001) ;
                    Serial.print("ADC0_A0_A1_Resistor:");Serial.println(ADC0_A0_A1_Resistor,3);
                    Serial.println("  ");
                  }
                  if ( buttonPushCounter == 0 && buttonPushCounterDigi == 1){
                  Serial.println("  ");
                  Serial.print("UP Button Pressed: value:"); Serial.println(sensorValue);
                    ADC0_A2_A3_Resistor = ADC0_A2_A3_Resistor + (0.001) ;
                    Serial.print("ADC0_A2_A3_Resistor:");Serial.println(ADC0_A2_A3_Resistor,3);
                    Serial.println("  ");
                  } 


                 if ( buttonPushCounter == 1 && buttonPushCounterDigi == 0){
                  Serial.println("  ");
                  Serial.print("UP Button Pressed: value:"); Serial.println(sensorValue);
                    ADC1_A0_A1_Resistor = ADC1_A0_A1_Resistor + (0.001) ;
                    Serial.print("ADC1_A0_A1_Resistor:");Serial.println(ADC1_A0_A1_Resistor,3);
                    Serial.println("  ");
                  }
                 if ( buttonPushCounter == 1 && buttonPushCounterDigi == 1){
                  Serial.println("  ");
                  Serial.print("UP Button Pressed: value:"); Serial.println(sensorValue);
                    ADC1_A2_A3_Resistor = ADC1_A2_A3_Resistor + (0.001) ;
                    Serial.print("ADC1_A2_A3_Resistor:");Serial.println(ADC1_A2_A3_Resistor,3);
                    Serial.println("  ");
                  } 
                  

                 if ( buttonPushCounter == 2 && buttonPushCounterDigi == 0){
                  Serial.println("  ");
                  Serial.print("UP Button Pressed: value:"); Serial.println(sensorValue);
                    ADC2_A0_A1_Resistor = ADC2_A0_A1_Resistor + (0.001) ;
                    Serial.print("ADC2_A0_A1_Resistor:");Serial.println(ADC2_A0_A1_Resistor,3);
                    Serial.println("  ");
                  }
                 if ( buttonPushCounter == 2 && buttonPushCounterDigi == 1){
                  Serial.println("  ");
                  Serial.print("UP Button Pressed: value:"); Serial.println(sensorValue);
                    ADC2_A2_A3_Resistor = ADC2_A2_A3_Resistor + (0.001) ;
                    Serial.print("ADC2_A2_A3_Resistor:");Serial.println(ADC2_A2_A3_Resistor,3);
                    Serial.println("  ");
                  } 


                 if ( buttonPushCounter == 3 && buttonPushCounterDigi == 0){
                  Serial.println("  ");
                  Serial.print("UP Button Pressed: value:"); Serial.println(sensorValue);
                    ADC3_A0_A1_Resistor = ADC3_A0_A1_Resistor + (0.001) ;
                    Serial.print("ADC3_A0_A1_Resistor:");Serial.println(ADC3_A0_A1_Resistor,3);
                    Serial.println("  ");
                  }
                 if ( buttonPushCounter == 3 && buttonPushCounterDigi == 1){
                  Serial.println("  ");
                  Serial.print("UP Button Pressed: value:"); Serial.println(sensorValue);
                    ADC3_A2_A3_Resistor = ADC3_A2_A3_Resistor + (0.001) ;
                    Serial.print("ADC3_A2_A3_Resistor:");Serial.println(ADC3_A2_A3_Resistor,3);
                    Serial.println("  ");
                  } 

      }
               
      else if (sensorValue <= 170){
      delay(30);        // Reads for stability
      Serial.println("  ");
      Serial.print("RIGHT Button Pressed: value:"); Serial.println(sensorValue);
      buttonPushCounter++;
      tft.fillScreen(ST77XX_BLACK);
      } 

      else  if (sensorValue <= 290){   
      delay(30);        // Reads for stability
        
                          if ( buttonPushCounter == 0 && buttonPushCounterDigi == 0){
                          Serial.println("  ");
                          Serial.print("DOWN Button Pressed: value:"); Serial.println(sensorValue);
                            ADC0_A0_A1_Resistor = ADC0_A0_A1_Resistor - (0.001) ;
                            Serial.print("ADC0_A0_A1_Resistor:");Serial.println(ADC0_A0_A1_Resistor,3);
                            Serial.println("  ");
                          }
                          if ( buttonPushCounter == 0 && buttonPushCounterDigi == 1){
                          Serial.println("  ");
                          Serial.print("DOWN Button Pressed: value:"); Serial.println(sensorValue);
                            ADC0_A2_A3_Resistor = ADC0_A2_A3_Resistor - (0.001) ;
                            Serial.print("ADC0_A2_A3_Resistor:");Serial.println(ADC0_A2_A3_Resistor,3);
                            Serial.println("  ");
                          } 
        
        
                         if ( buttonPushCounter == 1 && buttonPushCounterDigi == 0){
                          Serial.println("  ");
                          Serial.print("DOWN Button Pressed: value:"); Serial.println(sensorValue);
                            ADC1_A0_A1_Resistor = ADC1_A0_A1_Resistor - (0.001) ;
                            Serial.print("ADC1_A0_A1_Resistor:");Serial.println(ADC1_A0_A1_Resistor,3);
                            Serial.println("  ");
                          }
                         if ( buttonPushCounter == 1 && buttonPushCounterDigi == 1){
                          Serial.println("  ");
                          Serial.print("DOWN Button Pressed: value:"); Serial.println(sensorValue);
                            ADC1_A2_A3_Resistor = ADC1_A2_A3_Resistor - (0.001) ;
                            Serial.print("ADC1_A2_A3_Resistor:");Serial.println(ADC1_A2_A3_Resistor,3);
                            Serial.println("  ");
                          } 

                          
                         if ( buttonPushCounter == 2 && buttonPushCounterDigi == 0){
                          Serial.println("  ");
                          Serial.print("DOWN Button Pressed: value:"); Serial.println(sensorValue);
                            ADC2_A0_A1_Resistor = ADC2_A0_A1_Resistor - (0.001) ;
                            Serial.print("ADC2_A0_A1_Resistor:");Serial.println(ADC2_A0_A1_Resistor,3);
                            Serial.println("  ");
                          }
                         if ( buttonPushCounter == 2 && buttonPushCounterDigi == 1){
                          Serial.println("  ");
                          Serial.print("DOWN Button Pressed: value:"); Serial.println(sensorValue);
                            ADC2_A2_A3_Resistor = ADC2_A2_A3_Resistor - (0.001) ;
                            Serial.print("ADC2_A2_A3_Resistor:");Serial.println(ADC2_A2_A3_Resistor,3);
                            Serial.println("  ");
                          } 

                         if ( buttonPushCounter == 3 && buttonPushCounterDigi == 0){
                          Serial.println("  ");
                          Serial.print("DOWN Button Pressed: value:"); Serial.println(sensorValue);
                            ADC3_A0_A1_Resistor = ADC3_A0_A1_Resistor - (0.001) ;
                            Serial.print("ADC3_A0_A1_Resistor:");Serial.println(ADC3_A0_A1_Resistor,3);
                            Serial.println("  ");
                          }
                         if ( buttonPushCounter == 3 && buttonPushCounterDigi == 1){
                          Serial.println("  ");
                          Serial.print("DOWN Button Pressed: value:"); Serial.println(sensorValue);
                            ADC3_A2_A3_Resistor = ADC3_A2_A3_Resistor - (0.001) ;
                            Serial.print("ADC3_A2_A3_Resistor:");Serial.println(ADC3_A2_A3_Resistor,3);
                            Serial.println("  ");
                          } 
                          
      }

      else if (sensorValue <= 380 && sensorValue >= 360){
      delay(30);
      Serial.println("  ");
      Serial.print("LEFT  Button Pressed: value:"); Serial.println(sensorValue);
      buttonPushCounter--;
      tft.fillScreen(ST77XX_BLACK);
      }
      while (sensorValue <= 380){
      sensorValue = analogRead(A0);
      delay(20);
    }
   }

//>>>>>>>>>>>>>>>>>>>>>>>>>>>>>>>>>>>>>>>>>>>>>>
//>>>>>>>>>>>>>>>>>>>>>>>>>>>>>>>>>>>>>>>>>>>>>>
//>>>>>>>>>>>>>>>>>>>>>>>>>>>>>>>>>>>>>>>>>>>>>>
  //Mode 0, 1, 2 (Over 5 will be set to zero)

  if (buttonPushCounter > 5) {
    buttonPushCounter = 0;
  }
  if (buttonPushCounter < 0) {
    buttonPushCounter = 5;
  }
  
//>>>>>>>>>>>>>>>>>>>>>>>>>>>>>>>>>>>>>>>>>>>>>>
//>>>>>>>>>>>>>>>>>>>>>>>>>>>>>>>>>>>>>>>>>>>>>>
// Set timer as minutes to run follow script

    TimerNow = millis();
    Timer = TimerNow - TimerLast;
    
    TimerNow2 = millis();
    Timer2 = TimerNow2 - TimerLast2;
    
  if (Timer2 >1000 && buttonPushCounter == 0) {
    ADC0_CH1_CH2();
    TimerLast2 = TimerNow2;
  }
  if (Timer2 >1000 && buttonPushCounter == 1) {
    ADC1_CH1_CH2();
    TimerLast2 = TimerNow2;
  }
  if (Timer2 >1000 && buttonPushCounter == 2) {
    ADC2_CH1_CH2();
    TimerLast2 = TimerNow2;
  }
  if (Timer2 >1000 && buttonPushCounter == 3) {
    ADC3_CH1_CH2();
    TimerLast2 = TimerNow2;
  }
  if (Timer2 >1000 && buttonPushCounter == 4) {
    ADC_ALL();
    TimerLast2 = TimerNow2;
  }  
  if (Timer2 >1000 && buttonPushCounter == 5) {
    ADC_ALL2();
    TimerLast2 = TimerNow2;
  }

}

//>>>>>>>>>>>>>>>>>>>>>>>>>>>>>>>>>>>>>>>>>>>>>>
//>>>>>>>>>>>>>>>>>>>>>>>>>>>>>>>>>>>>>>>>>>>>>>
// Display 
//>>>>>>>>>>>>>>>>>>>>>>>>>>>>>>>>>>>>>>>>>>>>>>
//>>>>>>>>>>>>>>>>>>>>>>>>>>>>>>>>>>>>>>>>>>>>>>

// -----------------------------------------------------------------------------
// Different Group function
// -----------------------------------------------------------------------------

void ADC_ALL()
{
// Group1 //
    // Get Differential of A0-A1, and get single-end reading A1.
    adc0.setGain(ADS1115_PGA_0P256);
    float DiffV_ADC0_CH1 = 0;
    float IL_ADC0_CH1 = 0;
    int sensorOneCounts_ADC0_CH1 = adc0.getConversionP0N1(); 
    DiffV_ADC0_CH1 = sensorOneCounts_ADC0_CH1*adc0.getMvPerCount();
    IL_ADC0_CH1 = DiffV_ADC0_CH1 / ADC0_A0_A1_Resistor;

    //Get single-end V-load
    float SingleEnd_ADC0_CH1;
    adc0.setGain(ADS1115_PGA_6P144); adc0.setMultiplexer(ADS1115_MUX_P1_NG);
    SingleEnd_ADC0_CH1 = adc0.getConversionP1GND();  // counts up to 16-bits  
    SingleEnd_ADC0_CH1 = SingleEnd_ADC0_CH1*adc0.getMvPerCount() /1000;
    
    //Calculate PWR
    float PL_ADC0_CH1;
    PL_ADC0_CH1 = IL_ADC0_CH1 * SingleEnd_ADC0_CH1 ;  //  mA * V = mW

// Group2 //
    // Get Differential of A2-A3, and get single-end reading A1.
    adc0.setGain(ADS1115_PGA_0P256);
    float DiffV_ADC0_CH2 = 0;
    float IL_ADC0_CH2 = 0;
    int sensorOneCounts_ADC0_CH2 = adc0.getConversionP2N3();  // counts up to 16-bits  
    DiffV_ADC0_CH2 = sensorOneCounts_ADC0_CH2*adc0.getMvPerCount();
    IL_ADC0_CH2 = DiffV_ADC0_CH2 / ADC0_A2_A3_Resistor; // (0.2 ohm)

    //Get single-end V-load
    float SingleEnd_ADC0_CH2;
    adc0.setGain(ADS1115_PGA_6P144);
    adc0.setMultiplexer(ADS1115_MUX_P3_NG);
    SingleEnd_ADC0_CH2 = adc0.getConversionP3GND();  // counts up to 16-bits  
    SingleEnd_ADC0_CH2 = SingleEnd_ADC0_CH2*adc0.getMvPerCount() /1000;
    
    //Calculate PWR
    float PL_ADC0_CH2;
    PL_ADC0_CH2 = IL_ADC0_CH2 * SingleEnd_ADC0_CH2 ;  //  mA * V = mW

// Group1 //
    // Get Differential of A0-A1, and get single-end reading A1.
    adc1.setGain(ADS1115_PGA_0P256);
    float DiffV_ADC1_CH1 = 0;
    float IL_ADC1_CH1 = 0;
    int sensorOneCounts_ADC1_CH1 = adc1.getConversionP0N1(); 
    DiffV_ADC1_CH1 = sensorOneCounts_ADC1_CH1*adc1.getMvPerCount();
    IL_ADC1_CH1 = DiffV_ADC1_CH1 / ADC1_A0_A1_Resistor;

    //Get single-end V-load
    float SingleEnd_ADC1_CH1;
    adc1.setGain(ADS1115_PGA_6P144); adc1.setMultiplexer(ADS1115_MUX_P1_NG);
    SingleEnd_ADC1_CH1 = adc1.getConversionP1GND();  // counts up to 16-bits  
    SingleEnd_ADC1_CH1 = SingleEnd_ADC1_CH1*adc1.getMvPerCount() /1000;
    
    //Calculate PWR
    float PL_ADC1_CH1;
    PL_ADC1_CH1 = IL_ADC1_CH1 * SingleEnd_ADC1_CH1 ;  //  mA * V = mW
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

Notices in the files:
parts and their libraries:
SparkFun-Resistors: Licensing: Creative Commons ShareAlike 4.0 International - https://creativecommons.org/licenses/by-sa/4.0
